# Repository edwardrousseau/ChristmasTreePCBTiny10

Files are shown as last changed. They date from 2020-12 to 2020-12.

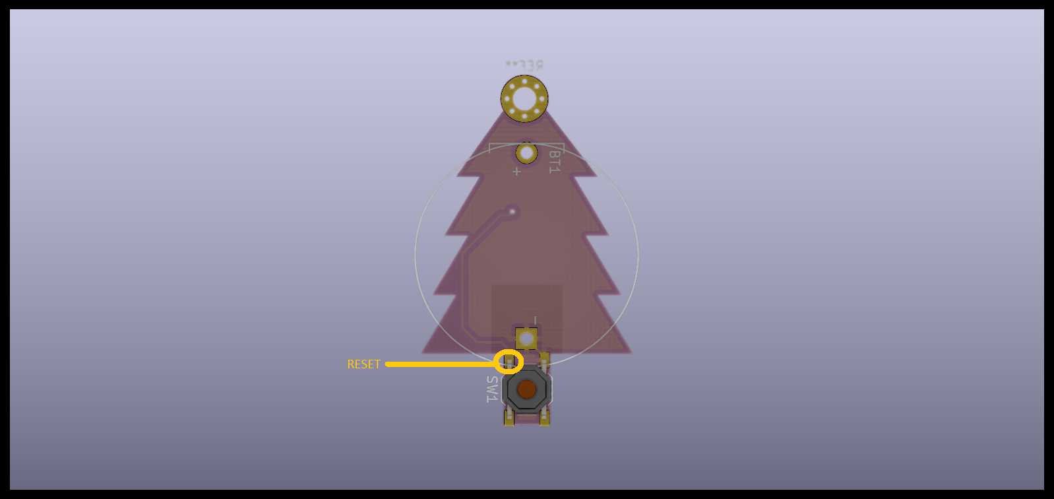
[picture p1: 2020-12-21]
Images/back_pregramming.png

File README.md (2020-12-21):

# Christmas tree with LEDs and Attiny4-5-9-10

## Getting Started

This is a christmas tree ornament that uses an Attiny and 3 LEDs. The power is supplied by a CR2032 battery.

## Requirements

* Arduino IDE version 1.8.3 (The attine10 core is not working on higher versions)
* [ATtiny10Core](https://github.com/technoblogy/attiny10core)
* USBASP programmer(Need recent firmware, will probably require an update if bought from eBay)

See [here](http://www.technoblogy.com/show?1YQY) to learn how to install the required software and program the MCU.

## Building
### Programming

The PCB does not include a programming port. It is possible to use an external programmer with a socket, or use one of the PCB as the programmer. 
To do it:

 1. Solder wires to one PCB as seen in the images folder (including RESET on the backside, 5 wires in total)
 2. Plug the wires in one end of the programmer's cable
 3. Disconnect the cable from the programmer
 4. Place the IC on the PCB, at the right place and in the right direction, and hold it with one hand
 5. With the other hand, plug the wire in the programmer
 6. Program with the Arduino IDE
 7. Disconnect the programmer's cable

### Assembling
* Start with the MCU.
* Continue with the leds (D*) and the resistors (R*). For the leds, the small green dot is the negative side and it goes in the "white box".
* Solder the battery holder. The + side is at the top.

## BOM

* PCB (Printed Circuit Boards, order from OSHPark or another supplier)
* MCU (Attiny4-5-9-10)
* 3 * 0805 1kOhm resistors
* 3 * 0805 LED (different colors)
* 2032 battery holder (with distance between pins of 20mm)

## Possible improvements
* Real pseudo-random LEDs pattern
* Add a small programming port
* Use a smaller battery so it is smaller than the board

## Author

* **Edward Rousseau** - *Initial work* - [Edward Rousseau](https://github.com/edwardrousseau)

## License

This project is licensed under the GPLv3 - see the [LICENSE](LICENSE) file for details

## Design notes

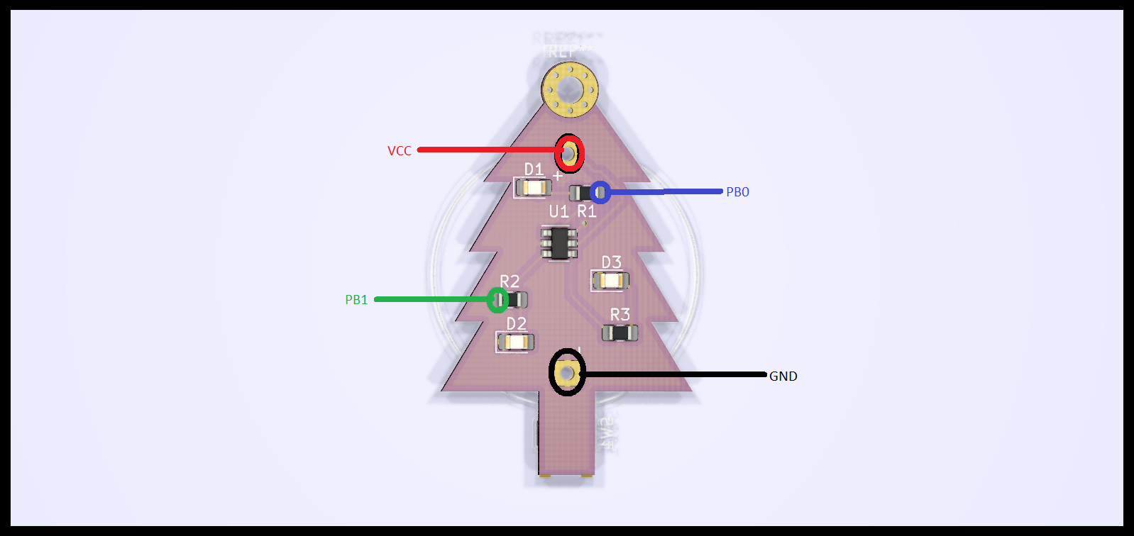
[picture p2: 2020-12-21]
Images/front_programming.png

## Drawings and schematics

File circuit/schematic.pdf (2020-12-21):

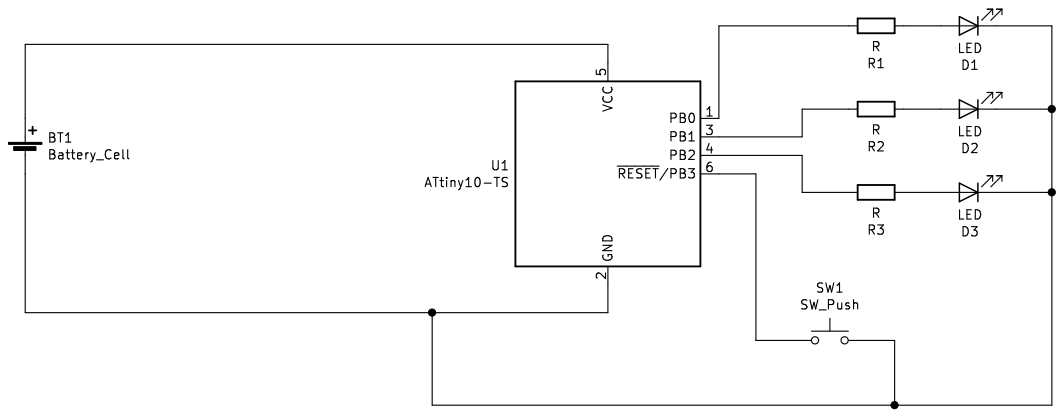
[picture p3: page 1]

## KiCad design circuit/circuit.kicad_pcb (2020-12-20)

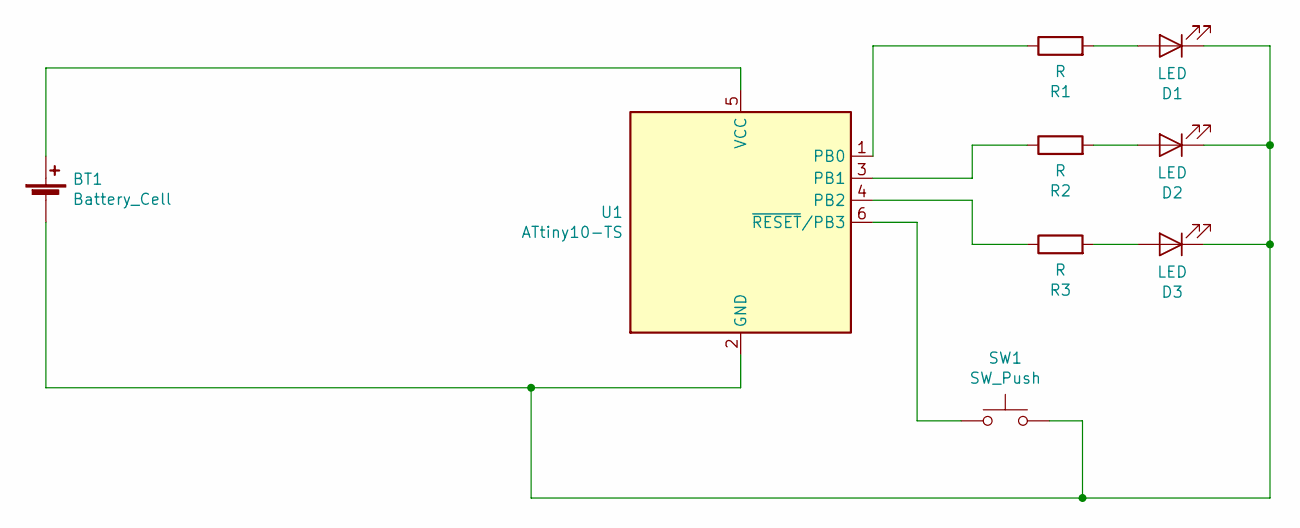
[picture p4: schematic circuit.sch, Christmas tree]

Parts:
BT1: Battery_Cell; battery
D1, D2, D3: LED; LED_0805_2012Metric_Pad1.15x1.40mm_HandSolder
R1, R2, R3: R; R_0805_2012Metric_Pad1.15x1.40mm_HandSolder
SW1: SW_Push; SW_SPST_TL3342
U1: ATtiny10-TS; SOT-23-6

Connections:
unnamed: BT1.1 (+), U1.5 (VCC)
unnamed: BT1.2 (-), D1.1 (K), D2.1 (K), D3.1 (K), SW1.2, U1.2 (GND)
unnamed: D1.2 (A), R1.2
unnamed: D2.2 (A), R2.2
unnamed: D3.2 (A), R3.2
unnamed: R1.1, U1.1 (PB0)
unnamed: R2.1, U1.3 (PB1)
unnamed: R3.1, U1.4 (PB2)
unnamed: SW1.1, U1.6 (~RESET~/PB3)

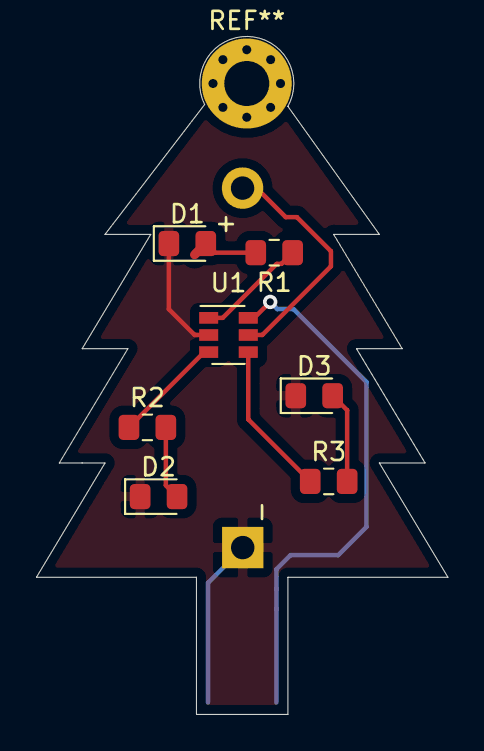
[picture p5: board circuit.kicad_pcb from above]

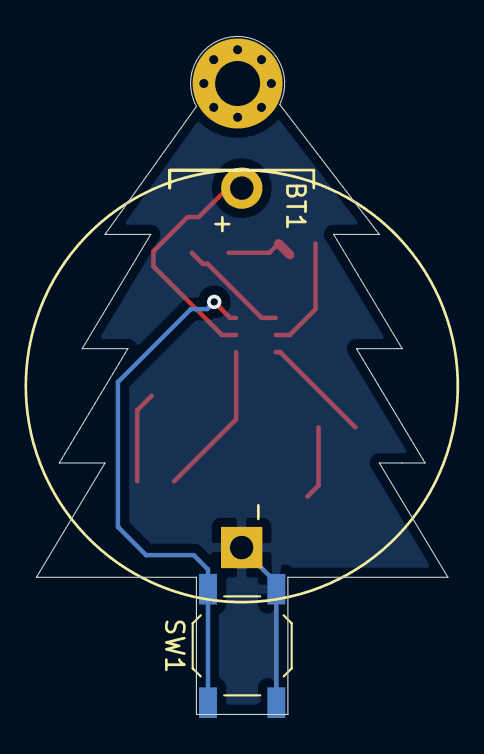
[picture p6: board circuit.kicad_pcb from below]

Board: 2 copper layers, 22.9 x 37.7 mm, 9 parts (2 on the bottom side), 9 nets.

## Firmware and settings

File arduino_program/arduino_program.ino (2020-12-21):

/*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
 *
 */


 /*
  * Program for Attiny4-5-9-10
  * Make the leds flash for 250ms every 4s on a fake random pattern
  */

#include <avr/io.h>
#include <stdint.h>
#include <avr/interrupt.h>
#include <avr/pgmspace.h>

volatile char i = 0; // Current index

const char array_led[] = {3, 1, 7, 4, 2, 3, 6, 1, 5, 2, 6, 3, 5, 2, 4, 1}; // Codes for ON leds (1=0B001, 2=0B010, ..., 7=0B111)
volatile char current_led;

int main (void) {
  sei(); //Enable interrupts
  CCP = 0xD8; // Unlock clock config
  CLKMSR = 0b01;  // 128 kHz WDT oscillator as clock source
  CCP = 0xD8; // Unlock clock config
  CLKPSR = 0b0111; // 128 clock prescaler, clock frequency = 1000 Hz -> 1 clock = 1 ms

  DDRB = 1 << DDB0 | 1 << DDB1 | 1 << DDB2;                 // PB0-2 as an output

  // Test leds
  PORTB = 0b111;
  __builtin_avr_delay_cycles(1000); // 1000 cycles = 1000 ms
  PORTB = 0b000;
  __builtin_avr_delay_cycles(1000);

  CCP = 0xD8; // Unlock watchdog config
  WDTCSR = 1 << WDIE | 1 << WDP3; // In interrupt mode, 4 s delay

  SMCR = 1 << SM1 | 1 << SE; // Select the deepest sleep mode
  __builtin_avr_sleep(); // Enable sleep
}

ISR(WDT_vect) //Interrupt on watchdog timer
{
  cli(); //Disable interrupts
  
  i = (i + 1); // Led turn on and turn off logic
  current_led = array_led[i & 0b1111];
  PORTB = current_led;
  __builtin_avr_delay_cycles(250); // 250 cycles = 250 ms
  PORTB = 0b000;

  sei(); //Enable interrupts
  SMCR = 1 << SM1 | 1 << SE; // Select the deepest sleep mode
  __builtin_avr_sleep(); // Enable sleep
}

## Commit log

2020-12-20 Update arduino_program.ino
    Add comments and GPLv3 license
2020-12-20 Update schematic info and use the good version
    Update schematic info and use the good version of the files, delete old Gerbers
    [circuit-B_Cu.gbr, circuit-B_Mask.gbr, circuit-B_Paste.gbr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]
2020-12-20 Correct battery polarity
    Correct battery polarity, update PCB info
    [circuit.kicad_pcb]
2020-12-20 Add Gerbers files and images
    [circuit-B_Cu.gbr, circuit-B_Mask.gbr, circuit-B_Paste.gbr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]
2020-12-21 PDF schematic
    [circuit.sch]

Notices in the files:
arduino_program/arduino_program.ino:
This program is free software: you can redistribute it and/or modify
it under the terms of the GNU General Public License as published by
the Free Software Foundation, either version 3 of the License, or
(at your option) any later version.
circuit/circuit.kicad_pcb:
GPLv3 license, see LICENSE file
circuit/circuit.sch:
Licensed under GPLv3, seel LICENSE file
